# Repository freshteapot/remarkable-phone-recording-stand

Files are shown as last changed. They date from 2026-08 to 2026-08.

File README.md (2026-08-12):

# reMarkable overhead phone recording stand

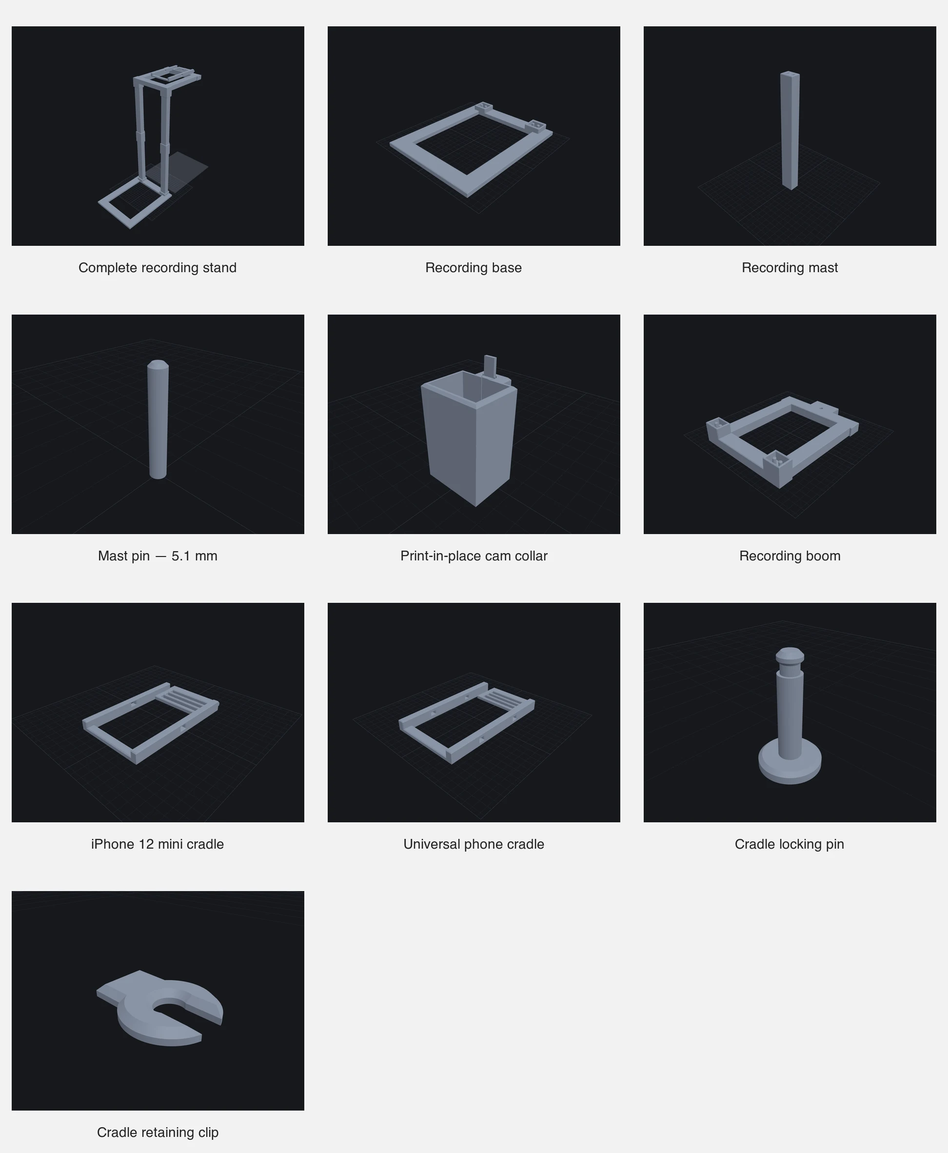
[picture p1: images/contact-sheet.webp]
Contact sheet showing the complete stand and printable components


A modular, fully 3D-printable tower that holds a phone above a portrait reMarkable 2 for recording handwriting and demonstrations. The tablet's left and right edges remain open, so the stand does not favour either writing hand.

The original conversational brief is preserved in [`SEED.md`](SEED.md). It explains why the stand is overhead, portrait-oriented and deliberately open on both writing sides.

## Project story

- [Read the design story](https://freshteapot.net/writing/designing-a-remarkable-recording-stand/)
- [Watch the build video on YouTube](https://youtube.com/shorts/me6PZGDw2Dk?feature=share)

> [!WARNING]
> This is a work in progress and the unballasted stand is top-heavy. **Do not place a phone overhead without substantial ballast across the rear of the base.** Keep the tablet and anything fragile out from underneath during initial testing. A heavy book is currently part of the operating setup.

## Current status

Physically printed and tested:

- Four mast segments
- 5.1 mm removable mast pins
- The 24.2 x 18.2 mm socket and its integral 5.2 mm dowels
- Print-in-place cam collar and its quarter-turn clamp
- 16 mm recording boom

Still awaiting complete-system validation:

- Finished base under full assembled load
- Phone retention while inverted and overhead
- Long recording sessions and vibration behaviour
- Formal tip/stability testing

Treat this release as an experimental build, inspect every printed part, and use it at your own risk.

## Printed parts

| File | Quantity | Purpose |
| --- | ---: | --- |
| `recording_base.stl` | 1 | Freestanding footprint; requires external ballast |
| `recording_mast.stl` | 4 | Two stacked segments per tower column |
| `mast_pin.stl` | 4 | 5.1 x 34 mm alignment pins for the two mast joints |
| `mast_cam_collar.stl` | 2 | Clamps around the two mid-column joints |
| `recording_boom.stl` | 1 | Twin-rail overhead frame |
| `iphone_12_mini_cradle.stl` | 1 | Fitted cradle for the original cased iPhone 12 mini |
| `phone_cradle.stl` | 1 optional | Universal alternative; print one cradle type, not both |
| `cradle_lock_pin.stl` | 1 | Tool-free cradle-to-boom pin |
| `cradle_retaining_clip.stl` | 2 | One working clip plus a spare |

Ready-to-slice models are in [`stl/`](stl/). Parametric nurb sources and their design-history cards are in [`source/parts/`](source/parts/).

## Important fit dimensions

- Mast section: 24 x 18 mm
- Base and boom sockets: 24.2 x 18.2 mm
- Integral base/boom dowels: 5.2 mm
- Removable mast pins: **5.1 mm**, 34 mm long
- Mast socket holes: 5.4 mm in the CAD model
- Tower-column spacing: 130 mm
- Two stacked mast segments: approximately 440 mm
- Boom thickness: 16 mm

The 5.1 and 5.2 mm values are deliberately different. Do not scale the parts in the slicer to adjust fit.

## Printing

The stand was developed for an Anycubic Kobra S1 Combo with a 250 x 250 x 250 mm build volume. The base is 190 x 230 mm and the corrected boom is 160 x 210 mm.

| Part | Orientation | Supports |
| --- | --- | --- |
| Base | Flat, as supplied | None |
| Mast | Upright | None |
| Mast pin | Upright on its full-width flat end | None |
| Cam collar | Upright | None |
| Boom | Flat with socket collars and integral dowels upward | None |
| Either phone cradle | Flat, as supplied | None |
| Cradle locking pin | Upright | None |
| Retaining clip | Flat | None |

PETG is preferred for the retaining clips because they flex during installation. PLA should be suitable for occasional assembly, but discard any clip that shows a crack. Use a structural profile you trust for the larger load-bearing parts.

The repository deliberately excludes G-code. Generate it for your own printer, material and slicer profile.

## Assembly

1. Place the base on a level, non-slip surface. Put substantial ballast across both rear feet, behind the mast line.
2. Insert the non-tapered ends of two lower masts into the base sockets. The base's integral 5.2 mm dowels enter the mast holes.
3. Slide one cam collar onto each lower mast before joining the upper segments.
4. Place two 5.1 mm mast pins in each mid-column joint. Insert each pin's **tapered end into the non-tapered mast end**; its flat end enters the externally tapered mast end.
5. Join the upper masts, centre each cam collar over its seam, and rotate its tab approximately 90 degrees until the joint is held firmly.
6. Flip the printed boom for assembly so its collars face downward. Lower it onto both upper mast ends; its four integral 5.2 mm dowels enter the mast sockets.
7. Join the selected phone cradle to the front of the boom with the locking pin. Snap the C-clip sideways into the narrow groove at the pin tip.
8. Retain the phone with elastic bands appropriate to the selected cradle.
9. Test the cradle and phone over something soft before mounting them on the tower. Then perform a gentle tip test with the tablet removed.

## Releasing the print-in-place cam

Do not twist harder if the cam's finger tab visibly bends.

1. Support the empty collar in your hand.
2. Push the bottom of the cam gently upward with a blunt 2–3 mm rod or Allen key.
3. The two tiny print bridges should shear with a small click.
4. Reseat the cam and confirm that it rotates freely before placing it on a mast.

The cam's flat side is the unlocked position. Turning the round side toward the mast applies the clamp pressure.

## Source files

The source uses [nurb](https://nurb.dev/), where each part is a parameterised Python function.

```sh
cd source
nurb dev
```

The complete preview is `mobile_recording_stand`. Each `.md` card beside a part records physical test results, rejected experiments and dimensions that should not be casually changed.

## Licence

The design, source and printable files are licensed under the [CERN Open Hardware Licence Version 2 – Strongly Reciprocal](LICENSE.txt).

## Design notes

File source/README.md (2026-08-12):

# Parametric source

This directory is a nurb project. Install nurb, then run:

```sh
nurb dev
```

Open the URL printed by the command and select `mobile_recording_stand` for the complete assembly.

Part dimensions are keyword defaults in the Python functions. Read the matching Markdown card before changing a part: its `Don't` section records failed physical tests and constraints that are not obvious from the geometry alone.

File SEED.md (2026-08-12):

# The seed

This project began with a simple request:

> We are going to print a custom stand for video recording via a mobile.
>
> I have a remarkable 2 tablet.
>
> I want to create a tower, stand, to place my iphone (mini 12) so it can record the screen.
>
> The phone would be placed in portrait mode.
>
> The tablet would sit natually in portrait mode.
>
> I am left handed, so perhaps we need to factor in where the supports are, to allow freedom of writing with the pen, for right or left handed people.

That seed led to a handed-neutral, modular recording tower developed through conversation, CAD iteration and physical fit tests. The imperfect wording is retained because this is the original brief, not a retrospective specification.

## Design principles that came from it

- Record the complete reMarkable 2 screen from directly overhead.
- Hold the phone in portrait orientation.
- Keep both writing edges of the tablet unobstructed.
- Work equally well for left- and right-handed writers.
- Fit within a 250 x 250 x 250 mm printer volume.
- Use printable, modular joints that can be tested and revised independently.

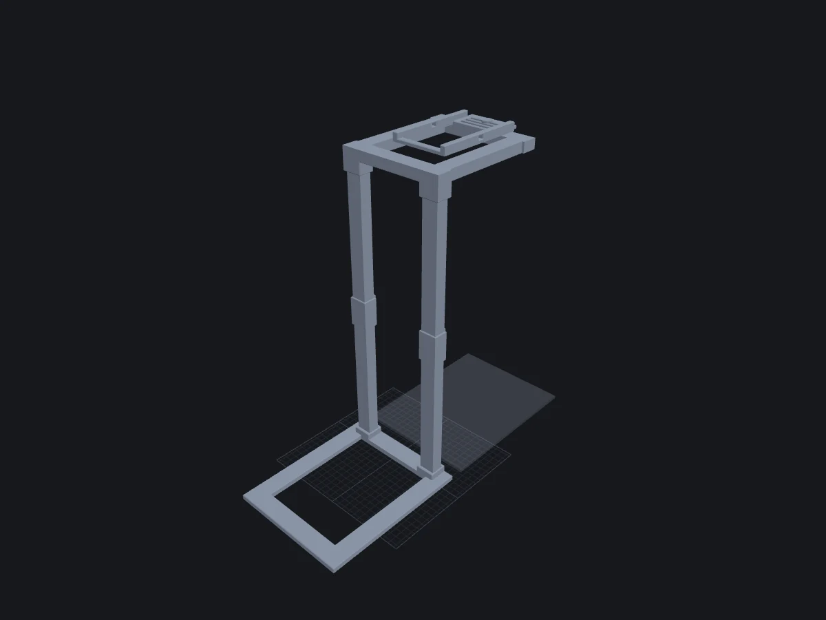
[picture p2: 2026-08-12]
images/complete-stand.webp

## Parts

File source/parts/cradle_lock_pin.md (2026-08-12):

# cradle_lock_pin

<!-- AUTO: regenerated by `nurb card`. Do not hand-edit. -->
Size: 16.00 x 16.00 x 29.30 mm, 1234.9 mm3, 1 solid, 11 faces
Checks: clean
<!-- /AUTO -->

## What it is

A broad-headed locking pin that replaces the M6 cradle bolt. Print one, plus a spare if desired.

## Design notes

The 5.8 mm shaft passes through the existing 6.4 mm cradle slots and boom hole. Its shoulder spans the 5 mm cradle mount and 16 mm boom with 0.3 mm axial clearance. A 4.4 mm neck near the lower tip receives the side-snapping retaining clip. The tip returns to full diameter through a support-free 45° flare, preventing the clip from falling off. The 16 mm head is large enough to pull out by hand.

## Don't

Do not enlarge the shaft past the existing 6.4 mm openings. Do not remove the reduced neck; it is the positive stop that prevents the clip sliding off the end.

## Changelog

- 2026-08-07: Added as a fully printed, tool-free replacement for the M6 bolt and wing nut.

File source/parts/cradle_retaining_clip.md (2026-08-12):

# cradle_retaining_clip

<!-- AUTO: regenerated by `nurb card`. Do not hand-edit. -->
Size: 17.68 x 14.00 x 2.00 mm, 271.2 mm3, 1 solid, 17 faces
Checks: clean
<!-- /AUTO -->

## What it is

A flat C-clip that snaps sideways into the cradle locking pin. Print one plus at least one spare.

## Design notes

The 4.7 mm inner opening runs freely around the pin's 4.4 mm groove. Its 4.2 mm entrance flexes open by 0.2 mm per side during insertion and then closes behind the neck. The opposite thumb tab has a deep structural overlap with the ring and makes removal possible without tools. Print flat as modelled; PETG is preferred for repeated flexing, though PLA should work for occasional assembly.

## Don't

Do not scale the clip in the slicer because that changes both retention and groove fit. Do not force a visibly cracked clip back into service; print the included spare.

## Changelog

- 2026-08-07: Added for the tool-free cradle joint.

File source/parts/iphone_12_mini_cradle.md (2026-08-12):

# iphone_12_mini_cradle

<!-- AUTO: regenerated by `nurb card`. Do not hand-edit. -->
Size: 86.60 x 152.00 x 13.00 mm, 41390.9 mm3, 1 solid, 85 faces
Slivers: 4 under 1.0mm2, smallest 0.866mm2, 4 accepted
Checks: clean
<!-- /AUTO -->

## What it is

The fitted everyday cradle for the user's cased iPhone 12 mini. It swaps onto the tower's standard tool-free locking-pin interface.

## Design notes

The 70.6 mm clear width uses the user's approximate 70 mm case measurement plus 0.6 mm removal clearance. The rear-camera area is open, and one elastic band through the central slots prevents lifting. Three lateral mount slots provide sideways and fore-aft adjustment so the selected lens can be centered over the reMarkable.

The case height and thickness remain provisional. Print and test this small cradle before gluing any tower joints.

Four sub-1 mm² faces are the expected corner triangles where three 1 mm polish chamfers meet.

## Don't

Do not remove the elastic retainer until the approximate case measurements have been proven. Do not add material to the upper-left camera region.

## Changelog

- 2026-08-07: Added as the default fitted cradle while retaining the universal cradle as an option.

```toml
[accepted]
sliver = 4
```

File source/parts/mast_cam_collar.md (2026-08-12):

# mast_cam_collar

<!-- AUTO: regenerated by `nurb card`. Do not hand-edit. -->
Size: 28.20 x 28.20 x 52.00 mm, 11588.7 mm3, 1 solid, 48 faces
Slivers: 14 under 1.0mm2, smallest 0.007mm2, 14 accepted
Checks: clean
<!-- /AUTO -->

## What it is

A physically proven print-in-place collar for the joint between two recording masts. Its smooth bore slides into position freely; a D-shaped cam turns to press both mast segments against the opposite wall.

## Design notes

The 44 mm collar grips 22 mm above and below the mast seam. Its normal opening is 24.2 x 18.2 mm, with no internal pressure bands. A vertical D-shaped cam runs through a reinforced boss on the front face. In the printed position the cam's flat faces the mast and clears it by 0.35 mm. Turning the finger tab a quarter-turn presents the round face and produces 0.15 mm nominal pressure.

The rotating member is a 5.4 mm D-shaped cam inside a 6.1 mm straight-through bearing. Its flat side provides 0.35 mm mast clearance in the printed position; presenting the round side adds the 0.15 mm squeeze. A vertical finger tab shows the flat's direction. Two 0.6 x 0.5 mm breakaway bridges connect the cam to the housing during printing so the STL remains one object. After printing, support the collar and push the bottom of the cam upward with a blunt 2–3 mm rod or Allen key; this shears the bridges without bending the finger tab. Reseat the cam, verify that it rotates freely, and only then fit the collar to a mast. The checker sees the deliberate 0.35 mm air gap as one thin section and the bridge/cam junctions as fourteen small faces; these are confined to the moving release mechanism, not structural walls.

Print upright, exactly as modelled, without supports. Physical testing on the Kobra S1 confirmed that the release clearance works and the quarter-turn cam holds the mast nicely once released and understood. The quarter-turn direction can be chosen by feel: turn until the mast is held firmly, without forcing the tab beyond its comfortable stop. Print two for the complete stand.

## Don't

Do not twist harder if the finger tab itself bends; push the cam upward from below to shear the release bridges. Do not lubricate or sand the cam before its first movement test; that would hide whether the 0.35 mm print-in-place clearance works on this printer. The cam is retained by gravity during normal upright use but can deliberately be lifted out for cleaning; do not mistake that serviceability for a failed print. Do not increase the physically proven cam pressure. Keep the simpler friction-band collar as a no-moving-parts fallback.

## Changelog

- 2026-08-09: Added a smooth-bore, print-in-place quarter-turn cam prototype at the user's request.
- 2026-08-09: Physical print test succeeded; recorded the safer push-from-below bridge release and promoted the cam collar to the production choice.

```toml
[part]
min_wall = 0.35 # Intentional print-in-place air gap; structural collar walls remain 2.0mm.

[accepted]
sliver = 14 # These bead-sized faces belong to the breakaway bridges and cam release junctions.
```

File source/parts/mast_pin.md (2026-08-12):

# mast_pin

<!-- AUTO: regenerated by `nurb card`. Do not hand-edit. -->
Size: 5.10 x 5.10 x 34.00 mm, 687.6 mm3, 1 solid, 4 faces
Checks: clean
<!-- /AUTO -->

## What it is

A 5.1 x 34 mm printed alignment pin for the stacked mast joint. Print four.

## Design notes

The lower mast's top socket is a full 18 mm cylinder, but the upper mast's bottom socket has a 45-degree conical roof required for support-free printing. The old 36 mm pin incorrectly treated both as fully usable 18 mm cylinders and could hold the mast faces apart. This pin is 34 mm long and retains approximately 17 mm engagement in each mast.

The pin prints upright on its full-width flat end. Its upper end receives a 1 mm taper. During assembly, insert the **tapered pin end into the non-tapered mast end**, whose internal socket has the conical roof; the flat pin end enters the externally tapered mast end, whose internal socket is fully cylindrical.

The first 5.0 mm model fit but wobbled slightly. A 5.2 mm revision initially improved the fit, but the latest shortened print felt too tight. The user confirmed 5.1 mm as the working new mast-pin diameter, so that is the production default for the 5.4 mm socket. The external mast joining collar handles residual joint rocking rather than increasing the pin diameter.

## Don't

Do not restore the 36 mm length: it ignores the usable-depth reduction from the bottom socket's conical roof and may prevent the mast faces from closing. Do not taper the print-bed end: the attempted double-taper pin produced a first-layer bevel and reduced the footprint of this tall, narrow print. Do not restore 5.2 mm as the production default after the user confirmed 5.1 mm for the new pin. Do not use a 5.3 mm pin: physical testing made it seize and break inside the stopped mast socket. Do not rely on one pin per mast joint; the pair prevents rotation.

## Changelog

- 2026-08-07: Added for the support-free stacked mast joint.
- 2026-08-07: Shortened from 40 to 36 mm to match the corrected stopped sockets.
- 2026-08-07: Increased diameter from 5.0 to 5.2 mm after the printed fit showed slight wobble.
- 2026-08-07: User confirmed the printed 5.2 mm pin fits much better; retained as the proven default.
- 2026-08-08: Added a 5.3 mm snug variant to test reduced rotational play throughout the tower.
- 2026-08-08: Removed the 5.3 mm variant after it seized and broke in a printed mast; 5.2 mm remains the maximum proven size.
- 2026-08-09: Shortened the pin to 34 mm after the unequal usable socket depths were confirmed on the printed masts.
- 2026-08-09: Rejected a double-ended taper because it weakened the print-bed footprint; retained one tapered end with explicit assembly orientation.
- 2026-08-09: Corrected an interpretation error and changed the production model diameter to the user-confirmed 5.1 mm.

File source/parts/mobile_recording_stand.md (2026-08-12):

# mobile_recording_stand

<!-- AUTO: regenerated by `nurb card`. Do not hand-edit. -->
Size: 190.00 x 496.00 x 479.00 mm, 1087847.7 mm3, 12 solids, 462 faces
Slivers: 44 under 1.0mm2, smallest 0.007mm2, 0 accepted
Checks: clean
<!-- /AUTO -->

## What it is

Assembly preview of a standalone, handed-neutral overhead phone tower for filming a portrait reMarkable 2.

## Design notes

The tablet is shown as a grey obstacle, not a printable part. The base stays entirely behind it, two columns rise 446 mm, and the fitted iPhone cradle sits approximately 466 mm above the desk. Print one base, four 5.1 mm mast pins, four masts, two print-in-place cam collars, one boom, one cradle locking pin, one retaining clip plus a spare, and either the fitted or universal cradle. Integral 5.2 mm dowels in the base enter the lower mast sockets. Each cam collar spans the seam between a lower and upper mast; its quarter-turn D-cam removes the sideways rocking that remains around the round pins and holds the collar in position. The boom prints with its socket collars and integral 5.2 mm alignment dowels upward, then flips over so the collars capture the mast tops and its dowels enter their upper sockets. One elastic band retains the phone in the fitted cradle (two for the universal cradle); no metal fastener is required.

The exact camera height is intentionally generous and may be reduced after a live framing test. The phone mount slides sideways so the selected rear lens is centered.

## Don't

Do not add tablet-side supports; the empty left and right edges are deliberate for both writing hands. Do not treat the grey tablet envelope as printable geometry. Do not permanently glue the mast joints before checking the camera framing. Do not increase the mast pins to remove wobble; 5.1 mm is the confirmed production pin and the cam collars carry the clamping job. Do not force a cam by bending its finger tab; release its print bridges by pushing upward from below first. Do not restore the M6 hardware requirement; the printed locking pin and clip are the standard cradle interface.

## Changelog

- 2026-08-07: Added modular printable assembly, fitted iPhone cradle, and optional universal cradle.
- 2026-08-07: Replaced the M6 bolt, washer, and wing nut with a printed locking pin and snap clip.
- 2026-08-08: Flipped the revised boom in assembly so its stopped socket collars engage the mast tops.
- 2026-08-08: Connected the boom positively to the upper mast sockets with four integral alignment dowels.
- 2026-08-08: Connected the base positively to the lower mast sockets with four matching integral alignment dowels.
- 2026-08-08: Added two slim mast joining collars to brace the pinned mid-column joints.
- 2026-08-09: Replaced the assembly's friction collars with the physically proven print-in-place cam collars.

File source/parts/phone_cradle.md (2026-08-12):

# phone_cradle

<!-- AUTO: regenerated by `nurb card`. Do not hand-edit. -->
Size: 104.00 x 186.00 x 16.00 mm, 70318.6 mm3, 1 solid, 110 faces
Slivers: 3 under 1.0mm2, smallest 0.866mm2, 3 accepted
Checks: clean
<!-- /AUTO -->

## What it is

An open universal phone carrier for overhead recording. Print one and retain the phone with two ordinary elastic bands.

## Design notes

The 84 x 174 x 14 mm envelope covers the iPhone 12 mini through iPhone 17 Pro Max and Pixel 10 Pro XL with moderate cases. A 14 mm lower ledge supports narrow phones; the upper-left rear-camera region stays completely open. Four slots take two replaceable elastic bands over the screen. Three 60 mm mount slots let an M6 bolt adjust both sideways and fore-aft for different rear-camera layouts, centering the selected lens rather than merely the phone body.

Three sub-1 mm² faces are expected corner triangles from the 1 mm polish pass.

## Don't

Do not use a fixed-width snap fit: it excludes future phones and printed springs creep. Do not add an upper-left support where it could enter an iPhone or Pixel camera view.

## Changelog

- 2026-08-07: Replaced the fixed iPhone cradle with an elastic-retained universal frame.

```toml
[accepted]
sliver = 3
```

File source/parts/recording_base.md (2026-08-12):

# recording_base

<!-- AUTO: regenerated by `nurb card`. Do not hand-edit. -->
Size: 190.00 x 230.00 x 18.00 mm, 169473.2 mm3, 1 solid, 79 faces
Slivers: 8 under 1.0mm2, smallest 0.866mm2, 8 accepted
Checks: clean
<!-- /AUTO -->

## What it is

The open, U-shaped footprint for the standalone recording tower. Print one.

## Design notes

The 230 mm rearward feet fit the 250 mm Kobra S1 bed and counterbalance the phone's forward reach without occupying either writing edge. The open middle saves material. Two 18 mm-deep bosses receive the full mast sections. Their revised 24.2 x 18.2 mm openings leave 0.2 mm total clearance around the 24 x 18 mm mast. Two integral 5.2 mm dowels in each socket engage 12 mm into the mast's existing bottom pin sockets, matching the proven pin fit.

Eight sub-1 mm² faces are the expected corner triangles from the 1 mm polish chamfers on the two socket bosses.

## Don't

Do not remove the internal dowels: the outer socket alone still permits perceptible movement. Do not restore the original 24.4 x 18.4 mm sockets; the printed fit wobbled. Do not extend feet beside the tablet; that would obstruct the writer's forearms and make the design handed. Do not narrow the footprint until a physical tip test has been performed with the heaviest target phone.

## Changelog

- 2026-08-07: First standalone base for the reMarkable overhead recorder.
- 2026-08-08: Tightened mast sockets from 0.4 to 0.2 mm total clearance after physical wobble was reported; added a fit coupon before any base reprint.
- 2026-08-08: Added twin integral dowels to each base socket and mirrored them in the fit coupon.

```toml
[accepted]
sliver = 8
```

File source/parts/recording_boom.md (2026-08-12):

# recording_boom

<!-- AUTO: regenerated by `nurb card`. Do not hand-edit. -->
Size: 160.00 x 210.00 x 34.00 mm, 261279.6 mm3, 1 solid, 88 faces
Slivers: 4 under 1.0mm2, smallest 0.866mm2, 4 accepted
Checks: clean
<!-- /AUTO -->

## What it is

The flat-printing twin-rail overhead boom. Print one.

## Design notes

The 177 mm reach is measured from the mast/socket centerline and places the selected rear camera over the center of a portrait reMarkable 2. A twin-rail rectangle resists torsion better than a single arm. Two 24.2 x 18.2 mm collars provide 14 mm of mast engagement and stop against the solid boom beam. Inside each collar, two integral 5.2 mm dowels engage 12 mm into the existing mast-end pin sockets. The collars and dowels print upward without support; flip the boom over during assembly so they face down. The 6.4 mm hole carries the printed tool-free cradle locking pin.

Four sub-1 mm² faces are the expected corner triangles where the 1 mm polish chamfers meet on the two socket collars.

## Don't

Do not remove the integral alignment dowels: without them, the boom merely rests on the mast collars while the visible mast-end holes do nothing. Do not restore the original through-sockets: they had no depth stop and could slide down the masts. Do not restore the original 24.4 x 18.4 mm mast clearance; it physically wobbled in the base. Do not replace this with one centered cantilever: it twists under off-axis camera weight. Do not add structure along the tablet sides.

## Changelog

- 2026-08-07: First centered twin-rail boom.
- 2026-08-07: Reused the original 6.4 mm mounting hole for the printed locking pin; no reprint was needed for this change.
- 2026-08-08: Tightened mast sockets to 0.2 mm total clearance to match the corrected base fit.
- 2026-08-08: Replaced through-sockets with stopped 14 mm collars; the boom now prints collars-up and assembles collars-down.
- 2026-08-08: Added twin integral dowels inside each collar to engage the existing upper-mast pin sockets.
- 2026-08-09: Re-centered the rear beam and collars on the mast datum; the previous assembly placed both boom sockets 12 mm forward of their masts.

```toml
[accepted]
sliver = 4
```

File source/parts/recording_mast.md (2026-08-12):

# recording_mast

<!-- AUTO: regenerated by `nurb card`. Do not hand-edit. -->
Size: 24.00 x 18.00 x 220.00 mm, 93413.8 mm3, 1 solid, 20 faces
Checks: clean
<!-- /AUTO -->

## What it is

A 220 mm stackable tower column. Print four.

## Design notes

Two segments make each 440 mm column while every print remains below the Kobra S1's 250 mm height. Each end has two separate 18 mm-deep sockets for the printed 5.0 mm alignment pins. The bottom sockets close with 45-degree conical roofs so they print support-free without becoming through-holes.

## Don't

Do not restore the original through-bores: the pins slipped straight through and could not locate the joint. Do not restore the narrow integral tongue: it caused the full-width mast to begin on air in the print orientation. Do not use a single column; the forward phone load would twist it.

## Changelog

- 2026-08-07: Replaced the unsupported tongue joint with twin alignment pins.
- 2026-08-07: Replaced continuous pin bores with stopped, support-free end sockets after the first printed mast exposed the slip-through fault.

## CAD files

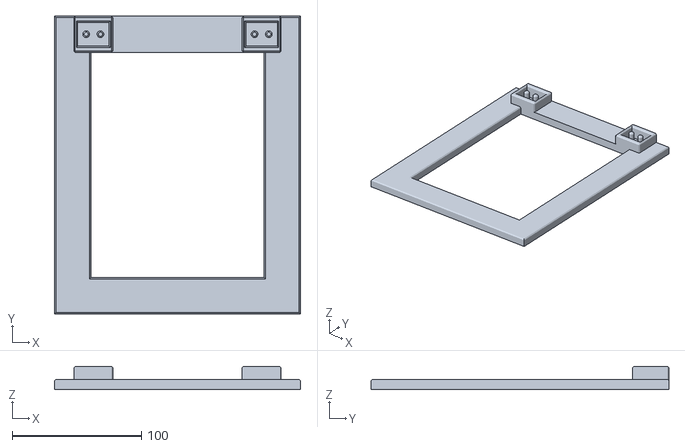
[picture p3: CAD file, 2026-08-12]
stl/recording_base.stl
190.0 x 230.0 x 18.0

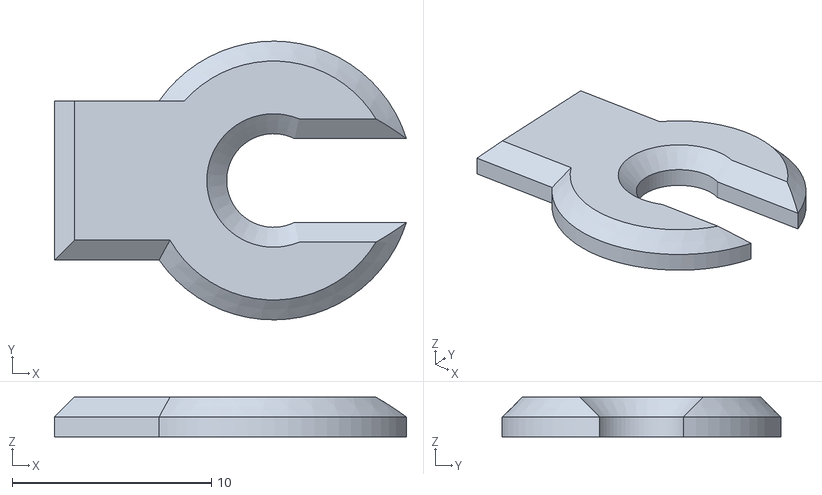
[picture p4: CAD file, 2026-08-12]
stl/cradle_retaining_clip.stl
17.7 x 14.0 x 2.00

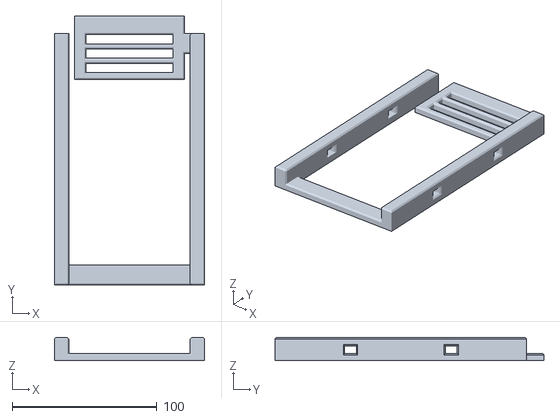
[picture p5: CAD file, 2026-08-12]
stl/phone_cradle.stl
104.0 x 186.0 x 16.0

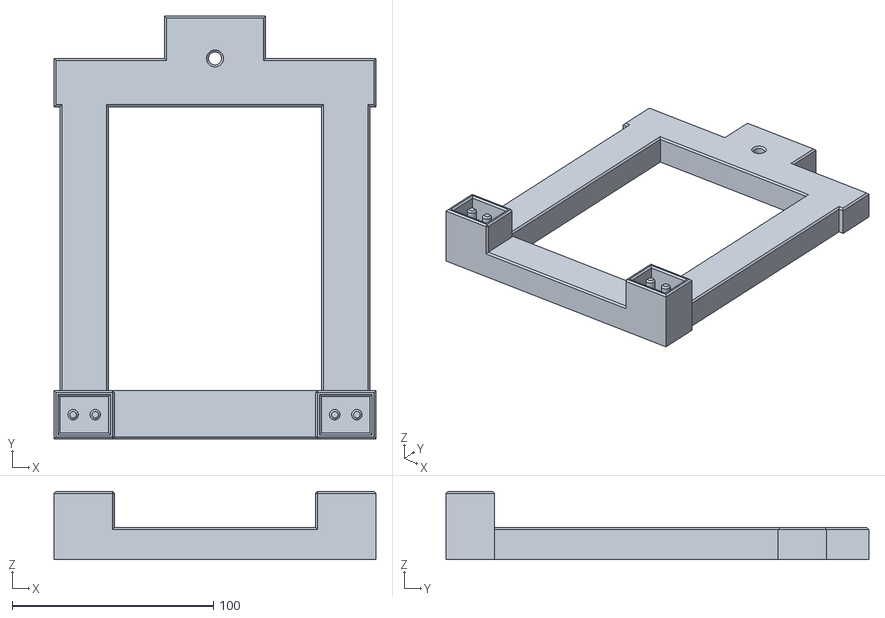
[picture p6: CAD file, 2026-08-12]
stl/recording_boom.stl
160.0 x 210.0 x 34.0

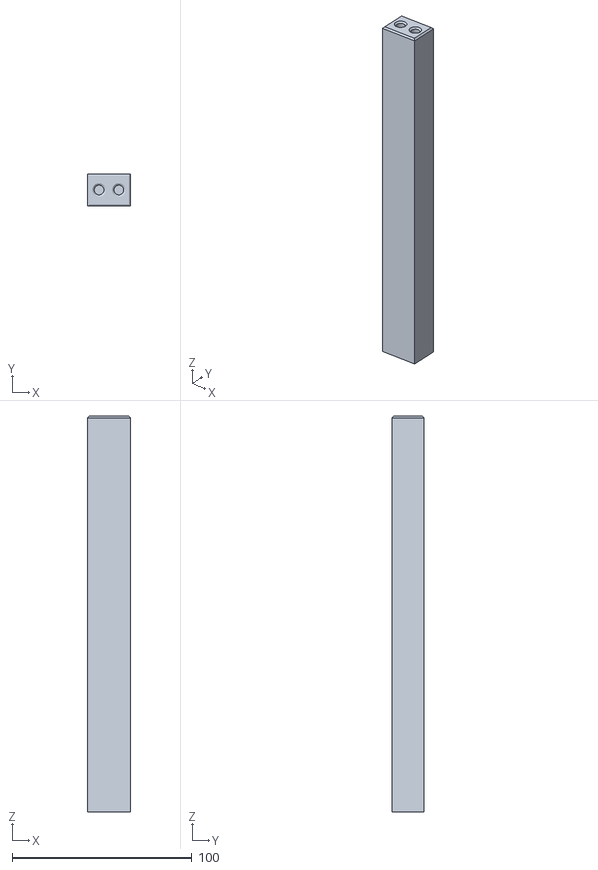
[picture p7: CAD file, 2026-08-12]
stl/recording_mast.stl
24.0 x 18.0 x 220.0

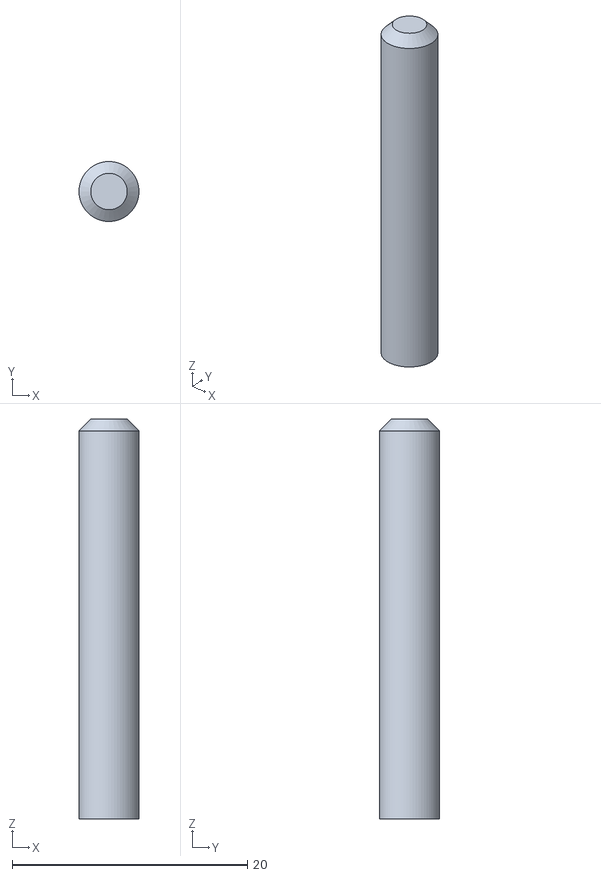
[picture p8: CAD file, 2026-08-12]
stl/mast_pin.stl
5.10 x 5.10 x 34.0

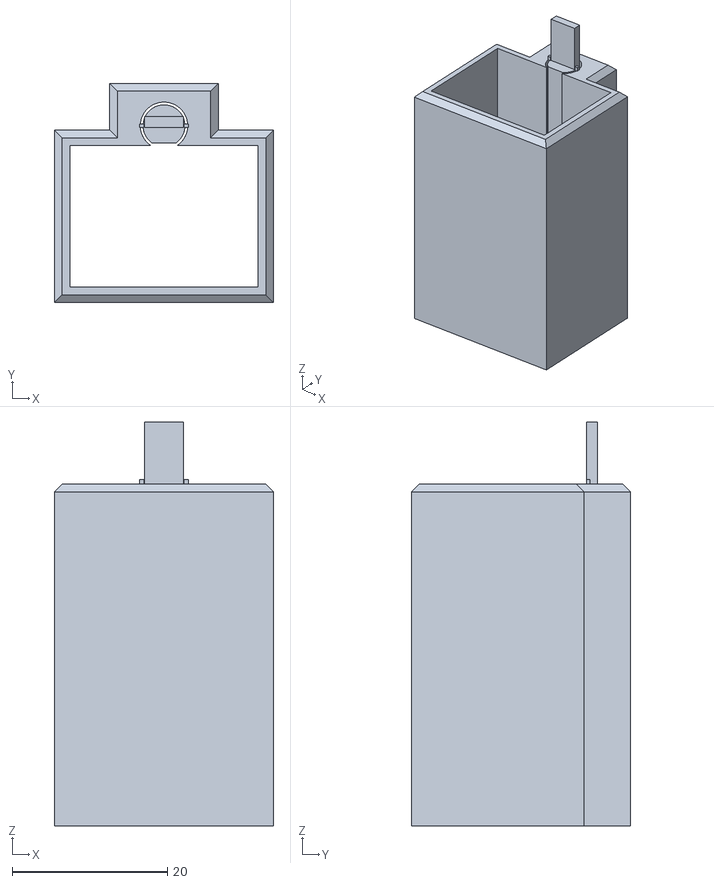
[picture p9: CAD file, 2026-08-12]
stl/mast_cam_collar.stl
28.2 x 28.2 x 52.0

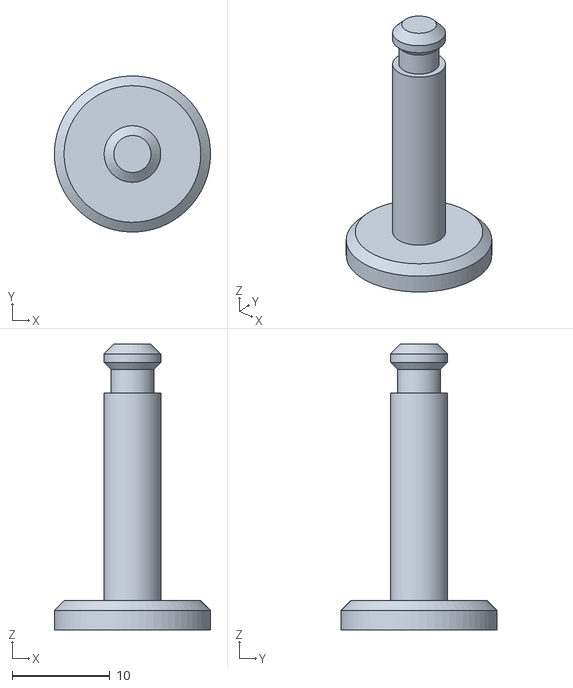
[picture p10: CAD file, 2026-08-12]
stl/cradle_lock_pin.stl
16.0 x 16.0 x 29.3

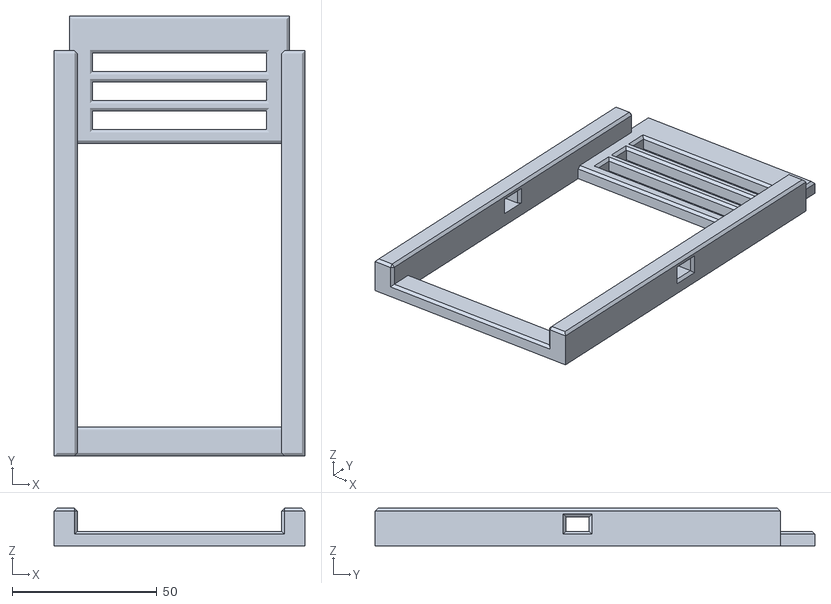
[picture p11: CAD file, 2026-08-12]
stl/iphone_12_mini_cradle.stl
86.6 x 152.0 x 13.0
